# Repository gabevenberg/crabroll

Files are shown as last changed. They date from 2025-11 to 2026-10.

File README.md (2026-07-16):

A Rust-based roller blind firmware compatible with [Home Assistant](https://www.home-assistant.io/) via the Home Assistant [MQTT cover](https://www.home-assistant.io/integrations/cover.mqtt/) integration.

## Hardware

The `hardware` directory contains a KiCad project with a basic through-hole-and-module board.
The major items you will need are a Stepstick-format TMC2209 (the one from [BTT](https://biqu.equipment/products/bigtreetech-tmc2209-stepper-motor-driver-for-3d-printer-board-vs-tmc2208) works fine) and a [Seedstudio esp32c3](https://www.seeedstudio.com/Seeed-XIAO-ESP32C3-p-5431.html).

You will also need:
* step down converter
    (the board is made for an Aliexpress one I had laying around using the MP-1584EN chip, but anything that can convert 9-24v down to 5v will work, given it can fit.)
* 4 2-pin pushbuttons
* 2 generic LEDs, one green one red
* handful of various THT resistors
* 100uF electrolytic cap
* some right-angle pin headers
* 5.5mm barrel jack
* 4 pin JST-XH socket
* power supply capable of supplying somewhere between 9-24v (depending on the torque you need out of your stepper) to a 5.5mm barrel plug
* either a reed switch and magnet or a microswitch.
* (optional) some pin header sockets, to socket your esp32c3 and tmc2209 for easy replacement.

The board assembly is straightforward.
The only thing you need to remember is that if your step down converter is adjustable,
adjust its output with a multimeter to 5v **BEFORE** you install the esp32c3.

For the installation onto the window,
it will require a bit of creativity on your part,
as every brand of blinds is different.
I use [this](https://www.printables.com/model/465889-minimalistic-motorized-roller-blinds-nema-17-stepp) mount to drive the blinds bead chain,
but depending on your exact model, you may be able to attach the motor shaft directly to the blinds.
Then, arrange for pins one and two of the right angle pin header (the one with the filled silkscreen is pin 1) to be shorted by a microswitch or a reed switch when the blinds are at their topmost position.
(pin 3 is 3.3v, for future hall effect sensor usage)

## Building

You will need:
* [rustup](https://rust-lang.org/tools/install/)
* [probe-rs](https://probe.rs/)

Then,

1. Install cargo with rustup (as described in the rustup link).
    You don't need to worry about having specific cross-compilation toolchains,
    the included `rust-toolchain.toml` file will take care of that for you.
    Also, if you use Nix flakes, I include a flake.nix with a devshell, so you can just run `nix shell`.
2. Copy `./crabroll/crabroll.example.toml` to `./crabroll/crabroll.toml`, and edit the values to match your environment.
   This means wifi SSID and password, MQTT credentials, and MQTT topics.
3. Still in the `crabroll` directory, and with your board plugged in via USB, run `cargo embed --release`.
    This will build Crabroll and flash it to the board.

## Home Assistant:

Add the following to your Home Assistant's `config.yaml`,
changing the `identifier` and `unique_id` as desired,
and changing the `position_topic` and `set_position_topic` to match your build.

```yaml
mqtt:
- cover:
    device:
      identifiers:
        crabroll
      manufacturer: Gabe
      model: v1
      name: crabroll
    device_class: blind
    qos: 0
    position_closed: 100 
    position_open: 0
    position_topic: crabroll/test/pos
    set_position_topic: crabroll/test/command
    unique_id: 01KEHE0KF2K00XCSSD2NK8PAS7_c3bfba9a3af04e1a9bbbece23a366ee8
```

## The physical interface:

Due to the stepper motor,
it is very important to *never pull on the blind chain or otherwise override the electronics*,
as that will cause Crabroll to lose track of its position.

Crabroll does come with a 4 button physical interface for cases when Home Assistant is unavailable or inconvenient.
The topmost button (with the barrel jack side being the bottom) will open the blinds when short pressed,
and will initiate the homing procedure when pressed for more than a second.
The green LED will flash when homing is finished.
The middle-top button and middle-bottom button will jog the blinds up and down, respectively.
The bottommost button will close the blinds fully when short pressed,
and when long pressed will set the current position as the bottom position and if storage is sucsessful, the green LED will flash.

On boot, the green LED will flash once after confirming flash storage is working.

In the case of an error, the red LED will flash, and depending on the error, Crabroll may reboot.
If caught in a bootloop, either the esp32 is dying, or there is a bug, and you should file an issue.

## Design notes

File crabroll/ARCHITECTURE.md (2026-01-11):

Crabroll is built on top of [Embassy](https://embassy.dev/) and [esp-hal](https://github.com/esp-rs/esp-hal).

It uses the embassy networking stack and [rust-mqtt](https://github.com/obabec/rust-mqtt) to manage communication with home assistant.
It uses a custom stepper motor driver (which will eventually be split into a standalone crate) to drive a stepper motor with a tmc2209 stepper motor driver.

Roughly, the architecture looks like:
```mermaid
flowchart
main[[main]]
main --o step_executor
main --o mqtt_handler & wifi_handler & button_handler & led_handler
subgraph stepper motor
step_executor[[step executor]]-->step_planner[step planner]
tmc_configurator[TMC2209 configuration driver]
end
subgraph physical interface
button_handler[[button handlers]]
led_handler[[led handler]]
end
subgraph networking
mqtt_handler[[MQTT listener]]
wifi_handler[[WiFi handler]]
end
mqtt_handler x--x step_executor
button_handler --x step_executor
step_executor --x led_handler
main --> tmc_configurator
```

```mermaid
flowchart
subgraph legend
task[[task]] -- spawns --o task2[[task]]
task[[task]] -- communicates with --x task2[[task]]
task -- calls --> function[function]
end
```

Main spawns all tasks,
and does the initial hardware setup,
as well as allocating resources and signals on the stack for communication between tasks.
Main also sets up the network stack.

The MQTT handler subscribes to relevant MQTT topics from home assistant,
sends commands as needed to the step executor,
and listens to position updates from teh step executor in order to publish MQTT position updates.

The wifi handler simply connects to wifi and attempts to reconnect whenever that connection is lost.

The step executor is a high-priority task that is responsible for the toggling of the TMC2209's step and dir pins.
It takes the target position from the MQTT listener,
and through iterating through the step planners step delays,
toggles the step pin at the correct timings to accelerate and decelerate the motor.

The step planner is a 'plain' struct with non-blocking, non-async methods,
which calculates acceleration curves for motor moves.

The TMC2209 configuration driver is an abstraction layer over the tmc2209's uart interface.
It is a bitfield based struct allowing configuration of things like microstepping, silent modes, and power saving modes.
It is a struct with async methods, which owns the uart interface connected to the TMC2209.

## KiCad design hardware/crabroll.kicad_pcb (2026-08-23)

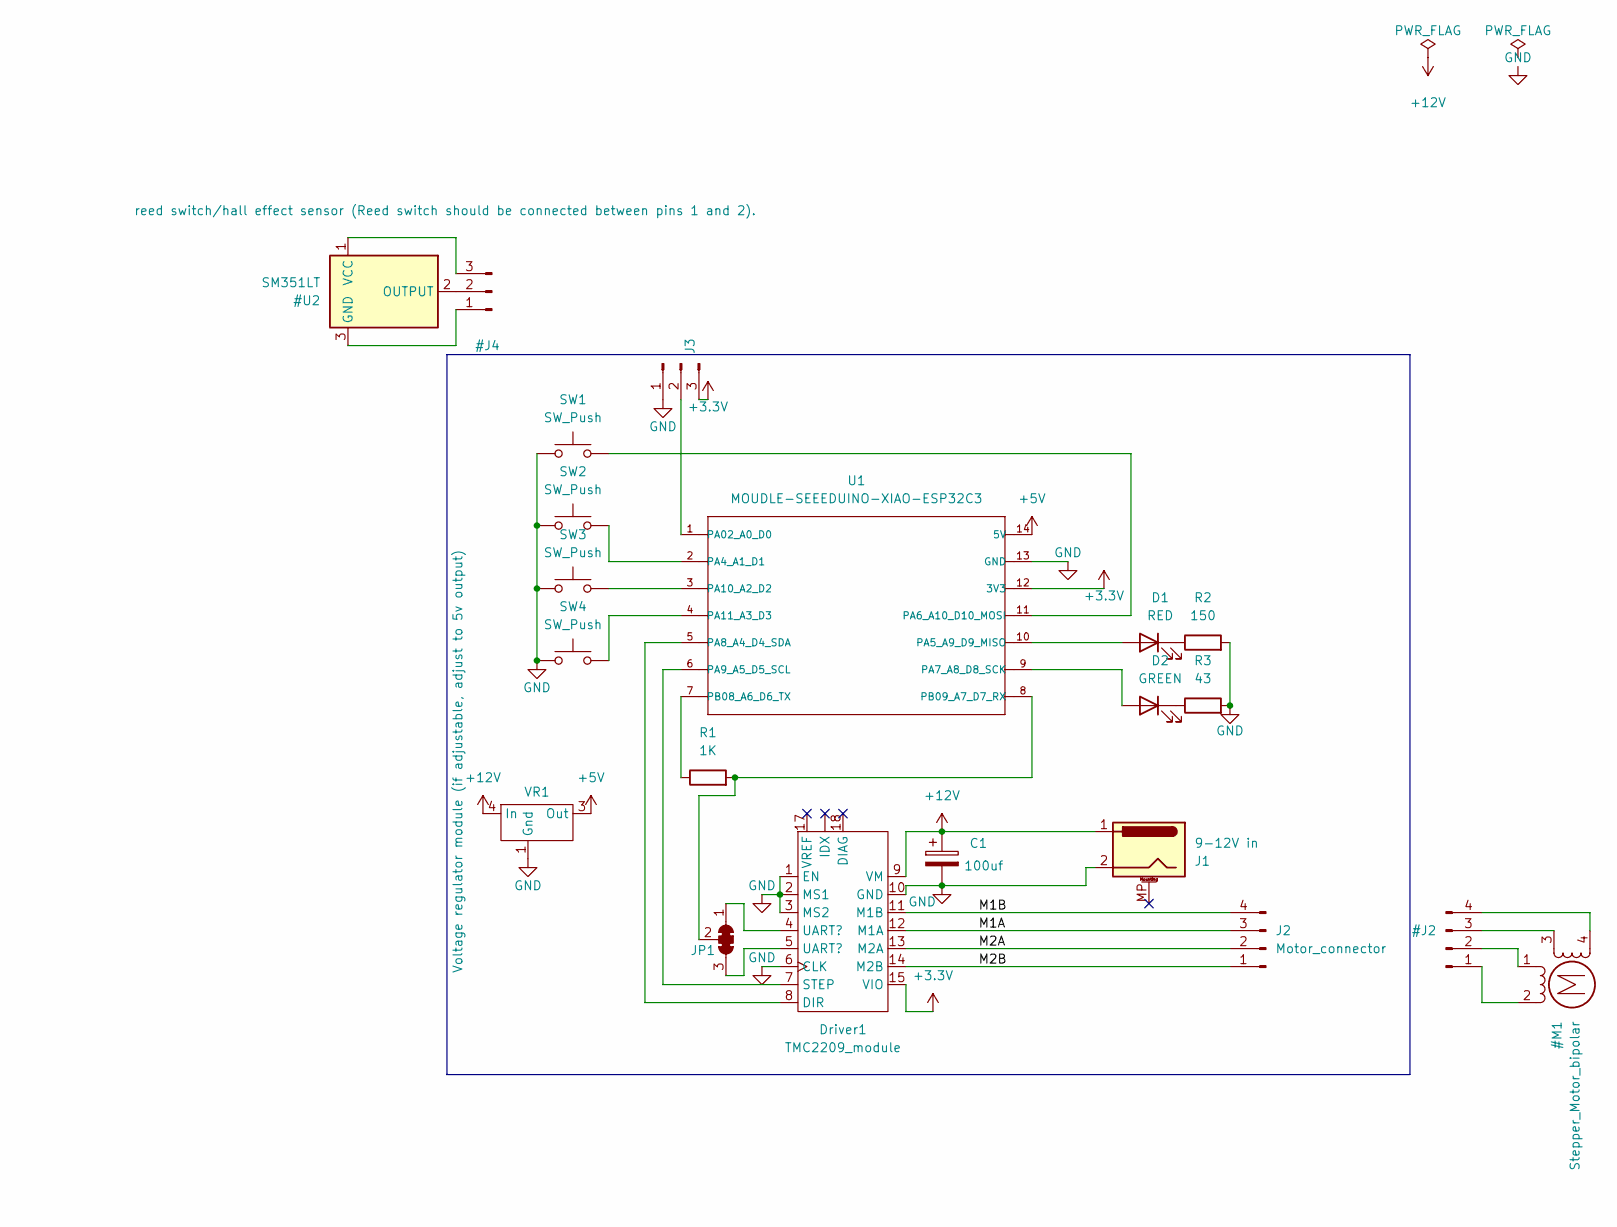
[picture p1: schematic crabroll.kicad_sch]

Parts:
C1: 100uf; CP_Radial_D6.3mm_P2.50mm
D1: RED; LED_D3.0mm
D2: GREEN; LED_D3.0mm
Driver1: TMC2209_module; Motor Driver Module
J1: 9-12V in; BarrelJack_Horizontal
J2: Motor_connector; JST_XH_S4B-XH-A_1x04_P2.50mm_Horizontal
J3: reed switch/hall effect sensor (Reed switch shoul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; PinHeader_1x03_P2.54mm_Horizontal
JP1: SolderJumper_3_Bridged123; SolderJumper-3_P1.3mm_Bridged123_RoundedPad1.0x1.5mm_Number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
R1: 1K; R_Axial_DIN0207_L6.3mm_D2.5mm_P10.16mm_Horizontal
R2: 150; R_Axial_DIN0207_L6.3mm_D2.5mm_P10.16mm_Horizontal
R3: 43; R_Axial_DIN0207_L6.3mm_D2.5mm_P10.16mm_Horizontal
SW1, SW2, SW3, SW4: SW_Push; Two_Pin_Through_Hole_Push_Button
U1: MOUDLE-SEEEDUINO-XIAO-ESP32C3; ESP32c3
VR1: Voltage regulator module (if adjustable, adjust t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; Voltage Regulator Module

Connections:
+3.3V: Driver1.15 (VIO), J3.3, U1.12 (3V3)
+5V: U1.14 (5V), VR1.3 (Out)
+12V: C1.1, Driver1.9 (VM), J1.1, VR1.4 (In)
/M1A: Driver1.12 (M1A), J2.3
/M1B: Driver1.11 (M1B), J2.4
/M2A: Driver1.13 (M2A), J2.2
/M2B: Driver1.14 (M2B), J2.1
GND: C1.2, Driver1.1 (EN), Driver1.2 (MS1), Driver1.3 (MS2), Driver1.6 (CLK), Driver1.10 (GND), Driver1.16 (GND), J1.2, J3.1, R2.2, R3.2, SW1.1, SW2.1, SW3.1, SW4.1, U1.13 (GND), VR1.1 (Gnd), VR1.2 (Gnd)
unnamed: D1.2 (A), U1.10 (PA5_A9_D9_MISO)
unnamed: D1.1 (K), R2.1
unnamed: D2.2 (A), U1.9 (PA7_A8_D8_SCK)
unnamed: D2.1 (K), R3.1
unnamed: Driver1.8 (DIR), U1.5 (PA8_A4_D4_SDA)
unnamed: Driver1.7 (STEP), U1.6 (PA9_A5_D5_SCL)
unnamed: J3.2, U1.1 (PA02_A0_D0)
unnamed: Driver1.4 (UART?), JP1.1 (A)
unnamed: Driver1.5 (UART?), JP1.3 (B)
unnamed: JP1.2 (C), R1.2, U1.8 (PB09_A7_D7_RX)
unnamed: SW2.2, U1.2 (PA4_A1_D1)
unnamed: SW1.2, U1.11 (PA6_A10_D10_MOSI)
unnamed: SW3.2, U1.3 (PA10_A2_D2)
unnamed: SW4.2, U1.4 (PA11_A3_D3)
unnamed: R1.1, U1.7 (PB08_A6_D6_TX)

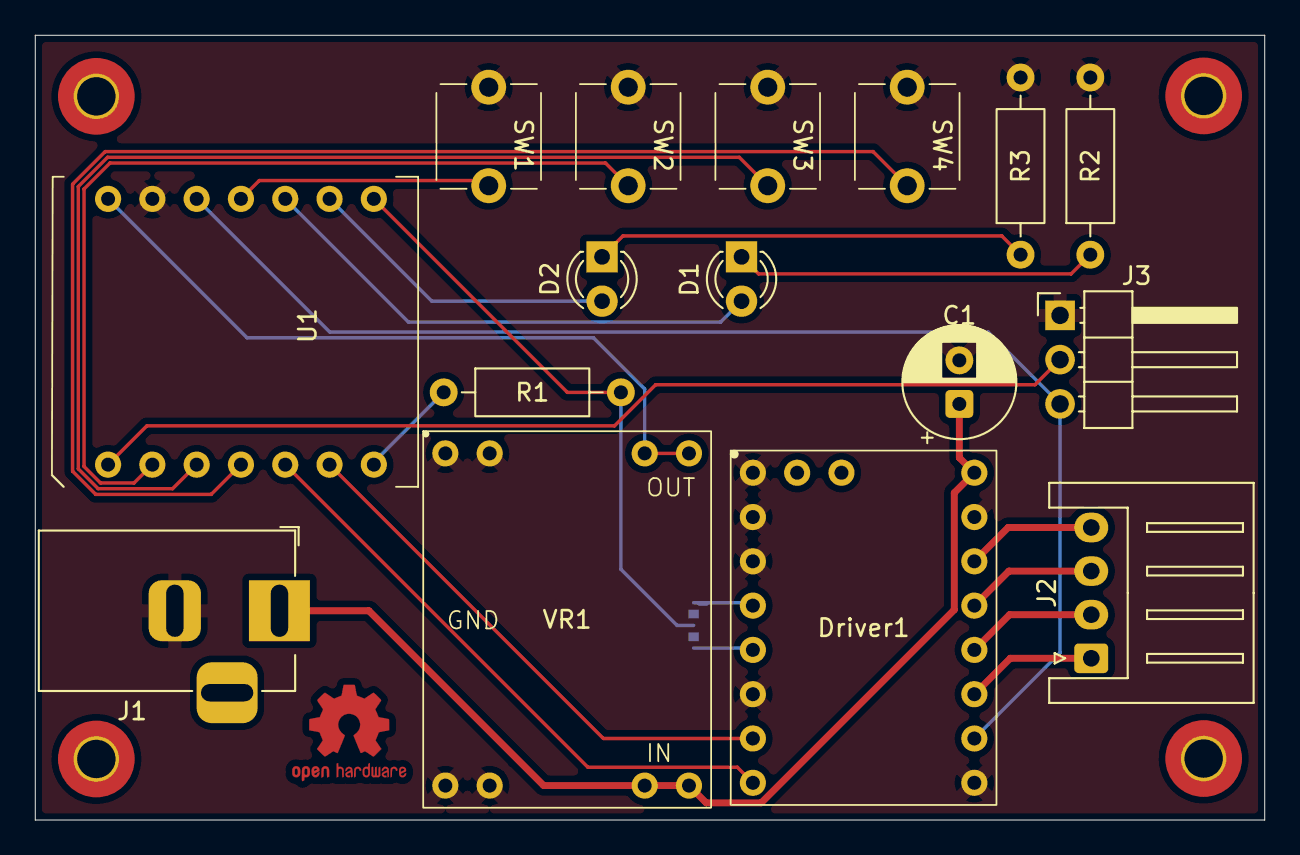
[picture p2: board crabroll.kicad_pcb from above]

Board: 2 copper layers, 70.5 x 45.0 mm, 17 parts (1 on the bottom side), 23 nets.

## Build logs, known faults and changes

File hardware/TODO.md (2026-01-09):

# for SMT version
[ ] Replace tmc2209 module with chip
[ ] replace regulator with LDO
[ ] replace the esp32c3 module with a chipdown solution
[ ] usb PD? unified USB port?

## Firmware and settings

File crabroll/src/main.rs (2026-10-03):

#![no_std]
#![no_main]
#![deny(
    clippy::mem_forget,
    reason = "mem::forget is generally not safe to do with esp_hal types, especially those \
    holding buffers for the duration of a data transfer."
)]
#![warn(clippy::all)]
#![allow(clippy::unusual_byte_groupings)]

mod motor;
mod mqtt;
mod tmc2209;
mod wifi;

use concrete_config::concrete_toml;
use defmt::{Format, info};
use defmt_rtt as _;
use embassy_executor::Spawner;
use embassy_net::StackResources;
use embassy_sync::{blocking_mutex::raw::CriticalSectionRawMutex, rwlock::RwLock, signal::Signal};
use embassy_time::{Duration, Instant, Timer};
use esp_alloc as _;
use esp_hal::{
    clock::CpuClock,
    gpio::{Input, InputConfig, Level, Output, OutputConfig, Pull},
    interrupt::{Priority, software::SoftwareInterruptControl},
    system::software_reset,
    timer::systimer::SystemTimer,
    uart::{Config, Uart},
};
use esp_radio::wifi::{ControllerConfig, sta::StationConfig};
use esp_rtos::embassy::InterruptExecutor;
use esp_storage::FlashStorage;
use iter_step_gen::Direction;
use panic_rtt_target as _;
use static_cell::StaticCell;
use tmc2209::Tmc2209;

use crate::{
    motor::motor_task,
    mqtt::mqtt_task,
    wifi::{connection, net_task},
};

#[concrete_toml("./crabroll.toml")]
mod config {
    #[root]
    pub struct Config {
        pub wifi: Wifi,
        pub mqtt: Mqtt,
    }

    pub struct Wifi {
        pub ssid: &'static str,
        pub password: &'static str,
    }

    pub struct Mqtt {
        pub username: &'static str,
        pub password: &'static str,
        pub broker_ip: &'static str,
        pub host_id: &'static str,
        pub topics: Topics,
    }

    pub struct Topics {
        pub command: &'static str,
        pub position: &'static str,
    }
}

esp_bootloader_esp_idf::esp_app_desc!();

#[esp_rtos::main]
async fn main(spawner: Spawner) {
    let config = esp_hal::Config::default().with_cpu_clock(CpuClock::max());
    let peripherals = esp_hal::init(config);

    esp_alloc::heap_allocator!(#[esp_hal::ram(reclaimed)] size: 64 * 1024);
    esp_alloc::heap_allocator!(size: 36 * 1024);

    let sw_int = SoftwareInterruptControl::new(peripherals.SW_INTERRUPT);
    let timer0 = SystemTimer::new(peripherals.SYSTIMER);
    esp_rtos::start(timer0.alarm0, sw_int.software_interrupt0);

    info!("Embassy initialized!");

    static EXECUTOR: StaticCell<InterruptExecutor<2>> = StaticCell::new();
    let step_executor = InterruptExecutor::new(sw_int.software_interrupt2);
    let step_executor = EXECUTOR.init(step_executor);
    let step_spawner = step_executor.start(Priority::Priority10);

    let step_pin = Output::new(peripherals.GPIO7, Level::Low, OutputConfig::default());
    let dir_pin = Output::new(peripherals.GPIO6, Level::Low, OutputConfig::default());
    let endstop_pin = Input::new(
        peripherals.GPIO2,
        InputConfig::default().with_pull(Pull::Up),
    );
    let green_led_pin = Output::new(peripherals.GPIO8, Level::Low, OutputConfig::default());
    let red_led_pin = Output::new(peripherals.GPIO9, Level::Low, OutputConfig::default());

    let home_button = Input::new(
        peripherals.GPIO5,
        InputConfig::default().with_pull(Pull::Up),
    );
    let raise_button = Input::new(
        peripherals.GPIO4,
        InputConfig::default().with_pull(Pull::Up),
    );
    let lower_button = Input::new(
        peripherals.GPIO3,
        InputConfig::default().with_pull(Pull::Up),
    );
    let bottom_button = Input::new(
        peripherals.GPIO10,
        InputConfig::default().with_pull(Pull::Up),
    );

    let flash = FlashStorage::new(peripherals.FLASH);

    info!("IO initialized!");

    let uart = Uart::new(
        peripherals.UART0,
        Config::default()
            .with_baudrate(115_200)
            .with_parity(esp_hal::uart::Parity::None),
    )
    .unwrap()
    .with_tx(peripherals.GPIO21)
    .with_rx(peripherals.GPIO20)
    .into_async();
    info!("UART initialized!");

    let mut tmc2209 = Tmc2209::new(uart, [true, false, false, false])
        .await
        .unwrap();

    // setup general config
    tmc2209.write_register(0, 0, 0b0111000100).await.unwrap();

    // set microstepping to fullstep
    tmc2209
        .write_register(0, 0x6c, 0b0001_1000_000000000000000110010011)
        .await
        .unwrap();

    // TODO: figure out why I need this, else we stall here.
    // Bug in the UART code/TMC?
    Timer::after_millis(1).await;

    // set current limiting
    tmc2209
        .write_register(0, 0x10, 0b1111_000_11000_000_00000)
        .await
        .unwrap();

    spawner.spawn(home_button_task(home_button).unwrap());
    spawner.spawn(raise_button_task(raise_button).unwrap());
    spawner.spawn(lower_button_task(lower_button).unwrap());
    spawner.spawn(bottom_button_task(bottom_button).unwrap());
    spawner.spawn(error_led_task(red_led_pin).unwrap());
    spawner.spawn(confirm_led_task(green_led_pin).unwrap());
    step_spawner.spawn(motor_task(step_pin, dir_pin, endstop_pin, flash).unwrap());

    info!("Motor tasks spawned!");

    let station_config = esp_radio::wifi::Config::Station(
        StationConfig::default()
            .with_ssid(config::CONFIG.wifi.ssid)
            .with_password(config::CONFIG.wifi.password.into()),
    );

    let (controller, interfaces) = esp_radio::wifi::new(
        peripherals.WIFI,
        ControllerConfig::default().with_initial_config(station_config),
    )
    .unwrap();

    let wifi_station = interfaces.station;

    let config = embassy_net::Config::dhcpv4(Default::default());

    let rng = esp_hal::rng::Rng::new();
    let seed = (rng.random() as u64) << 32 | rng.random() as u64;

    static STACK_RESOURCES: StaticCell<StackResources<3>> = StaticCell::new();
    let stack_resources = STACK_RESOURCES.init_with(StackResources::<3>::new);

    // Init network stack
    let (stack, runner) = embassy_net::new(wifi_station, config, stack_resources, seed);

    spawner.spawn(connection(controller).unwrap());
    spawner.spawn(net_task(runner).unwrap());
    spawner.spawn(mqtt_task(stack).unwrap());
}

#[derive(Eq, PartialEq)]
enum Command {
    Home,
    StartJog(Direction),
    StopJog,
    SetBottom,
    MoveToPos(i8),
}

#[derive(Eq, PartialEq, Format)]
enum ErrorSeverity {
    Soft,
    Hard,
}

static DIR_TO_HOME: RwLock<CriticalSectionRawMutex, Level> = RwLock::new(Level::Low);
static LAST_COMMAND: Signal<CriticalSectionRawMutex, Command> = Signal::new();
// in percentage, if -1, current position is unknown. Should also try to replace with an atomic.
static CURRENT_POS: Signal<CriticalSectionRawMutex, i8> = Signal::new();
//TODO: Surely theres a way to use an atomicbool here? The main thing is we need to be able to
//await it.
static ERROR_SIGNAL: Signal<CriticalSectionRawMutex, ErrorSeverity> = Signal::new();
static CONFIRM_SIGNAL: Signal<CriticalSectionRawMutex, ()> = Signal::new();

#[embassy_executor::task]
async fn error_led_task(mut led: Output<'static>) {
    loop {
        let error = ERROR_SIGNAL.wait().await;
        led.set_high();
        Timer::after_secs(1).await;
        led.set_low();
        match error {
            ErrorSeverity::Soft => (),
            ErrorSeverity::Hard => software_reset(),
        }
    }
}

#[embassy_executor::task]
async fn confirm_led_task(mut led: Output<'static>) {
    loop {
        CONFIRM_SIGNAL.wait().await;
        led.set_high();
        Timer::after_secs(1).await;
        led.set_low();
    }
}

#[embassy_executor::task]
async fn home_button_task(mut button: Input<'static>) {
    loop {
        button.wait_for_low().await;
        let start_press = Instant::now();
        Timer::after_millis(50).await;
        button.wait_for_high().await;
        if start_press.elapsed() > Duration::from_secs(1) {
            LAST_COMMAND.signal(Command::Home);
            info!("home button long pushed");
        } else {
            LAST_COMMAND.signal(Command::MoveToPos(0));
            info!("home button pushed");
        }
        Timer::after_millis(50).await;
    }
}

#[embassy_executor::task]
async fn raise_button_task(mut button: Input<'static>) {
    loop {
        button.wait_for_low().await;
        info!("raise button pushed");
        LAST_COMMAND.signal(Command::StartJog(Direction::ToHome));
        Timer::after_millis(50).await;
        button.wait_for_high().await;
        LAST_COMMAND.signal(Command::StopJog);
        Timer::after_millis(50).await;
    }
}

#[embassy_executor::task]
async fn lower_button_task(mut button: Input<'static>) {
    loop {
        button.wait_for_low().await;
        info!("lower button pushed");
        LAST_COMMAND.signal(Command::StartJog(Direction::AwayFromHome));
        Timer::after_millis(50).await;
        button.wait_for_high().await;
        LAST_COMMAND.signal(Command::StopJog);
        Timer::after_millis(50).await;
    }
}

#[embassy_executor::task]
async fn bottom_button_task(mut button: Input<'static>) {
    loop {
        button.wait_for_low().await;
        let start_press = Instant::now();
        Timer::after_millis(50).await;
        button.wait_for_high().await;
        if start_press.elapsed() > Duration::from_secs(1) {
            LAST_COMMAND.signal(Command::SetBottom);
            info!("bottom button long pushed");
        } else {
            LAST_COMMAND.signal(Command::MoveToPos(100));
            info!("bottom button pushed");
        }
        Timer::after_millis(50).await;
    }
}

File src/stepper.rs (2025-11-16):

use core::{iter::FusedIterator, num::NonZeroU32};

use defmt::Format;
use embassy_time::{Duration, TICK_HZ};
use thiserror::Error;

#[derive(Format, Debug, Clone, Copy, Error)]
pub enum StepperError {
    #[error("Attempted move out of bounds")]
    MoveOutOfBounds,
    #[error("Attempted a planned move while not homed")]
    NotHomed,
}

#[derive(Format, Debug, Clone, Copy, PartialEq, Eq)]
pub enum Direction {
    Cw,
    Ccw,
}

impl Direction {
    fn opposite(self) -> Self {
        match self {
            Direction::Cw => Direction::Ccw,
            Direction::Ccw => Direction::Cw,
        }
    }
}

// a trapezoidal stepper planner that implements the algorithm described
// [here](http://hwml.com/LeibRamp.pdf), modified for use with integer math.

///Trapezoidal stepper planner.
///Does not move anything on its own,
///but allows you to construct 'step plans', which are iterators over Durations.
#[derive(Format, Debug)]
pub struct Stepper {
    // in steps. (0 is at home)
    travel_limit: NonZeroU32,
    // steps/sec
    max_speed: NonZeroU32,
    //steps/sec^2
    max_accel: NonZeroU32,
    // steps/sec (this is the velocity the stepper motor instantly jumps to from rest and instantly
    // stops when it reaches it.)
    start_vel: u32,
    // Direction to home in.
    dir_to_home: Direction,
    curent_pos: Option<u32>,
    // precomputed delay between steps 1 and 2.
    inital_delay: u64,
    // precomputed maximum stopping distance
    max_stopping_distance: u32,
    // delay between steps when at max speed.
    cruise_delay: Duration,
    // inverse of (R) from the paper.
    accel_divisor: u64,
}

impl Stepper {
    ///Creates new stepper motor instance.
    ///units:
    ///Travel_limit: max steps from home the stepper motor can safely travel.
    ///max_speed: max steps/sec the stepper motor can safely rotate.
    ///max_accel: max steps/sec^2 the stepper motor can achieve.
    ///dir_to_home: the direction the motor spins when moving towards home.
    pub fn new(
        travel_limit: NonZeroU32,
        max_speed: NonZeroU32,
        max_accel: NonZeroU32,
        start_vel: u32,
        dir_to_home: Direction,
    ) -> Self {
        Self {
            travel_limit,
            max_speed,
            max_accel,
            start_vel,
            dir_to_home,
            curent_pos: None,
            inital_delay: Self::compute_inital_delay(start_vel, max_accel),
            max_stopping_distance: Self::compute_max_stopping_distance(
                max_speed, start_vel, max_accel,
            ),
            cruise_delay: Self::compute_cruise_delay(max_speed),
            accel_divisor: Self::compute_accel_devisor(max_accel),
        }
    }

    const fn compute_accel_devisor(max_accel: NonZeroU32) -> u64 {
        (TICK_HZ ^ 2) / max_accel.get() as u64
    }

    const fn compute_inital_delay(start_vel: u32, max_accel: NonZeroU32) -> u64 {
        TICK_HZ / ((start_vel as u64 ^ 2) + 2 * max_accel.get() as u64).isqrt()
    }

    const fn compute_max_stopping_distance(
        max_speed: NonZeroU32,
        start_vel: u32,
        max_accel: NonZeroU32,
    ) -> u32 {
        ((max_speed.get() ^ 2) - (start_vel ^ 2)) / (2 * max_accel.get())
    }

    const fn compute_cruise_delay(max_speed: NonZeroU32) -> Duration {
        Duration::from_hz(max_speed.get() as u64)
    }

    pub fn homing_move<'a, F: FnMut() -> bool>(
        &'a mut self,
        endstop_fn: F,
    ) -> (HomingMove<'a, F>, Direction) {
        let delay = Duration::from_ticks(self.inital_delay);
        let dir = self.dir_to_home;
        (
            HomingMove {
                stepper: self,
                delay,
                endstop_fn,
                steps_moved: 0,
            },
            dir,
        )
    }

    //TODO: Refactor as a typestate for the NotHomed check?
    pub fn planned_move<'a>(
        &'a mut self,
        target_pos: u32,
    ) -> Result<(PlannedMove<'a>, Direction), StepperError> {
        match self.curent_pos {
            None => Err(StepperError::NotHomed),
            Some(_) if target_pos > self.travel_limit.get() => Err(StepperError::MoveOutOfBounds),
            Some(current_pos) => {
                let move_distance: u32 = current_pos.abs_diff(target_pos);

                let stopping_distance = if move_distance > self.max_stopping_distance * 2 {
                    self.max_stopping_distance
                } else {
                    move_distance / 2
                };

                let dir = if current_pos < target_pos {
                    self.dir_to_home
                } else {
                    self.dir_to_home.opposite()
                };
                Ok((
                    PlannedMove {
                        stepper: self,
                        phase: Phase::Accelerate,
                        stopping_distance,
                        prev_delay: Duration::MIN,
                        steps_to_travel: move_distance,
                        dir,
                    },
                    dir,
                ))
            }
        }
    }

    pub fn continuous_jog<'a, F: FnMut() -> bool>(
        &'a mut self,
        continue_fn: F,
        dir: Direction,
    ) -> Result<(ContinuousJog<'a, F>, Direction), StepperError> {
        match self.curent_pos {
            Some(_) => {
                let delay = Duration::from_ticks(self.inital_delay);
                Ok((
                    ContinuousJog {
                        stepper: self,
                        delay,
                        continue_fn,
                        dir,
                    },
                    dir,
                ))
            }
            None => Err(StepperError::NotHomed),
        }
    }

    /// Returns the travel limit of this [`Stepper`] in steps.
    pub fn travel_limit(&self) -> NonZeroU32 {
        self.travel_limit
    }

    /// Sets the travel limit of this [`Stepper`] in steps.
    pub fn set_travel_limit(&mut self, travel_limit: NonZeroU32) {
        self.travel_limit = travel_limit;
    }

    /// Returns the max speed of this [`Stepper`] in steps/sec.
    pub fn max_speed(&self) -> NonZeroU32 {
        self.max_speed
    }

    /// Sets the max speed of this [`Stepper`] in steps/sec.
    pub fn set_max_speed(&mut self, max_speed: NonZeroU32) {
        self.max_speed = max_speed;
        self.max_stopping_distance =
            Self::compute_max_stopping_distance(max_speed, self.start_vel, self.max_accel);
        self.cruise_delay = Self::compute_cruise_delay(max_speed);
    }

    /// Returns the max accel of this [`Stepper`] in steps/sec^2.
    pub fn max_accel(&self) -> NonZeroU32 {
        self.max_accel
    }
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

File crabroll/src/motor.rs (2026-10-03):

use core::{iter::FusedIterator, num::NonZeroU32};

use super::LAST_COMMAND;
use crate::{CONFIRM_SIGNAL, CURRENT_POS, Command, DIR_TO_HOME, ERROR_SIGNAL, ErrorSeverity};

use defmt::{error, info};
use embassy_embedded_hal::adapter::BlockingAsync;
use embassy_time::{Duration, Timer};
use esp_bootloader_esp_idf::partitions::{
    self, DataPartitionSubType, PARTITION_TABLE_MAX_LEN, PartitionType,
};
use esp_hal::gpio::{Input, Output};
use esp_storage::FlashStorage;
use iter_step_gen::{Direction, Stepper, StepperError};
use sequential_storage::{
    cache::Cache,
    map::{MapConfig, MapStorage},
};

const DEFAULT_TRAVEL_LIMIT: NonZeroU32 = NonZeroU32::new(2048).unwrap();
const MAX_VEL: NonZeroU32 = NonZeroU32::new(128).unwrap();
const MAX_ACCEL: NonZeroU32 = NonZeroU32::new(64).unwrap();
const START_VEL: u32 = 64;
const BACKLASH_COMP: u32 = 10;

// storage consts
const TRAVEL_LIMIT_KEY: u8 = 0;

#[embassy_executor::task]
pub(crate) async fn motor_task(
    mut step_pin: Output<'static>,
    mut dir_pin: Output<'static>,
    endstop_pin: Input<'static>,
    mut flash: FlashStorage<'static>,
) {
    let mut pt_mem = [0u8; PARTITION_TABLE_MAX_LEN];
    let pt = partitions::read_partition_table(&mut flash, &mut pt_mem).unwrap();
    let nvs = pt
        .find_partition(PartitionType::Data(DataPartitionSubType::Nvs))
        .unwrap()
        .unwrap();
    let partition = nvs.as_embedded_storage(&mut flash);
    let mut flash = MapStorage::<u8, _, _>::new(
        BlockingAsync::new(partition),
        MapConfig::new(0x0000..0x6000),
        Cache::new_uncached(),
    );

    let mut flash_buffer = [0u8; 4096];
    let travel_limit = match flash
        .fetch_item::<u32>(&mut flash_buffer, &TRAVEL_LIMIT_KEY)
        .await
    {
        Ok(Some(l)) => {
            CONFIRM_SIGNAL.signal(());
            NonZeroU32::new(l).unwrap()
        }
        Ok(None) => {
            match flash
                .store_item(
                    &mut flash_buffer,
                    &TRAVEL_LIMIT_KEY,
                    &DEFAULT_TRAVEL_LIMIT.get(),
                )
                .await
            {
                Ok(()) => {
                    CONFIRM_SIGNAL.signal(());
                }
                Err(_) => {
                    error!("Error storing item in flash");
                    ERROR_SIGNAL.signal(ErrorSeverity::Hard);
                }
            };
            DEFAULT_TRAVEL_LIMIT
        }
        Err(_) => {
            error!("Error getting item in flash");
            ERROR_SIGNAL.signal(ErrorSeverity::Hard);
            DEFAULT_TRAVEL_LIMIT
        }
    };

    let mut stepper = Stepper::new(travel_limit, MAX_VEL, MAX_ACCEL, START_VEL);
    execute_home(&mut step_pin, &mut dir_pin, &mut stepper, &endstop_pin).await;
    loop {
        match LAST_COMMAND.wait().await {
            Command::Home => {
                info!("homing");
                execute_home(&mut step_pin, &mut dir_pin, &mut stepper, &endstop_pin).await;
                CONFIRM_SIGNAL.signal(());
                info!("homed");
                update_pos(&stepper);
            }
            Command::StartJog(direction) => {
                info!("jogging in {} direction", direction);
                match execute_jog(&mut step_pin, &mut dir_pin, &mut stepper, direction).await {
                    Ok(_) => {
                        info!("jogged");
                        update_pos(&stepper);
                        compensate_backlash(&mut stepper, &mut step_pin, &mut dir_pin).await;
                    }
                    Err(e) => {
                        info!("Error: {}", e);
                        ERROR_SIGNAL.signal(ErrorSeverity::Soft);
                    }
                };
            }
            // should be unreachable.
            Command::StopJog => (),
            Command::SetBottom => {
                if let Some(pos) = stepper.pos() {
                    info!("Setting current position as bottom");
                    let pos = NonZeroU32::new(pos).unwrap_or(NonZeroU32::MIN);
                    stepper.set_travel_limit(pos);
                    match flash
                        .store_item(&mut flash_buffer, &TRAVEL_LIMIT_KEY, &pos.get())
                        .await
                    {
                        Ok(()) => CONFIRM_SIGNAL.signal(()),
                        Err(_) => {
                            error!("Error storing item in flash");
                            ERROR_SIGNAL.signal(ErrorSeverity::Hard);
                        }
                    };
                    update_pos(&stepper);
                } else {
                    info!("Attempted to set travel limit while unhomed");
                    ERROR_SIGNAL.signal(ErrorSeverity::Soft);
                }
            }
            Command::MoveToPos(percent) => {
                info!("moving to {}", percent);
                let pos = (percent as u32 * stepper.travel_limit().get()) / 100_u32;
                info!("moving to {}", pos);
                match execute_move(&mut step_pin, &mut dir_pin, &mut stepper, pos).await {
                    Ok(_) => {
                        info!("moved to pos");
                        update_pos(&stepper);
                        compensate_backlash(&mut stepper, &mut step_pin, &mut dir_pin).await;
                    }
                    Err(e) => {
                        info!("Error: {}", e);
                        ERROR_SIGNAL.signal(ErrorSeverity::Soft);
                    }
                };
            }
        }
    }
}

async fn compensate_backlash<'a>(
    stepper: &mut Stepper,
    step_pin: &mut Output<'a>,
    dir_pin: &mut Output<'a>,
) {
    if let Some(p) = stepper.pos() {
        match execute_move(step_pin, dir_pin, stepper, p.saturating_sub(BACKLASH_COMP)).await {
            Ok(_) => info!("let out backlash"),
            Err(e) => {
                info!("Error: {}", e);
                ERROR_SIGNAL.signal(ErrorSeverity::Soft);
            }
        };
    };
}

fn update_pos(stepper: &Stepper) {
    CURRENT_POS.signal(if let Some(p) = stepper.pos() {
        ((p * 100_u32) / stepper.travel_limit())
            .try_into()
            .unwrap_or(100)
    } else {
        0
    });
}

async fn execute_home<'a>(
    step_pin: &mut Output<'a>,
    dir_pin: &mut Output<'a>,
    stepper: &mut Stepper,
    endstop_pin: &Input<'a>,
) {
    dir_pin.set_level(*DIR_TO_HOME.read().await);
    let plan = stepper.homing_move(|| endstop_pin.is_low());
    execute_step_plan(step_pin, plan).await;
}
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

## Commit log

2025-07-21 testing communicating with tmc2209 over uart.
2025-07-22 broke out 2209 uart stuff into own module.
    [main.rs, tmc2209.rs]
2025-07-25 added wifi connectivity.
    Board will now maintain connection to a wifi network specified at
    build-time.
2025-07-27 first stepper movment, verify register reads with ifcnt register.
2025-11-10 start of final (tm) write
    removing wifi stuff for now,
    added pin definitions based on new breadboard.
2025-11-16 stepper motor motion planning done, though it needs testing.
    That will probably require breaking it out into its own crate.
2025-11-18 split out stepper step gen into seperate crate.
2025-11-23 Fixed the formula to work with integers, wrote documentation explaining the algorithm.
    [lib.rs]
2025-11-23 Improved precision of step algorithm, still overshoots slightly.
    [lib.rs]
2025-11-28 fixed acceleration, worked around off-by-2 error in stopping distance.
    [lib.rs]
2025-11-29 fixed fusediterator stuff.
2025-12-04 hooked up iter-step-gen to motor test.
2025-12-04 added current limiting to demo.
2025-12-13 use high-priority executor for stepper motor.
2025-12-14 found bug in my uart code, not sure whats causing it.
    [main.rs]
2026-01-01 Button interactivity.
2026-01-01 Crabroll hardware v1 added. Just made from parts I have on hand.
    [crabroll.kicad_pcb, crabroll.kicad_sch]
2026-01-01 proof of concept wifi while also maintaining button interactivity.
2026-01-04 added actions for long-press of the buttons.
2026-01-05 added task for the red 'error' LED.
    [main.rs, motor.rs]
2026-01-11 Fleshed out readme, along with some minor changes:
    * MQTT facing position is now from 0-255 instead of 0-100.
    * the 'bottom' of the board is now facing the barrel jack, buttons have
    been reassigned accordingly.
    Fixes #4
    [main.rs, motor.rs]
2026-01-11 Basic network retry logic, really messy, must fix later.
    [main.rs]
2026-01-12 cleanup and fixing lints, adding todo items.
    [lib.rs, main.rs, motor.rs]
2026-01-15 Changed MQTT command and position to be strings, rather than single byte numbers
    Home assistant templates really arent cut out for decoding binary data,
    unfortunately. At least I dont have to decode and encode JSON.
2026-01-22 added persistent storage of bottom position.
    Fixes #7.
    Also added a reason for the green LED to be there!
    [main.rs, motor.rs]
2026-08-12 increased motor current, decreased speeds.
2026-08-23 motor tuning for real world use. Increased torque, decreased speed.
2026-08-23 kicad version update.
    [crabroll.kicad_pcb, crabroll.kicad_sch]
2026-08-23 added backlash compensation.
    makes sure the motor doesnt have tension on it when the tmc2209 powers
    it down.
    [motor.rs]
2026-09-11 Corrected initial delay, broke out leibramp calc.
    [lib.rs]
2026-10-03 Fixed deceleration distance logic by simulating once at construction.
    [lib.rs, main.rs, motor.rs]
